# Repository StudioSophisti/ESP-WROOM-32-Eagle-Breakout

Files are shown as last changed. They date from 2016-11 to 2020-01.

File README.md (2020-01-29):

# ESP-WROOM-32-Eagle-Breakout
A breadboard compatible Eagle breakout board for Espressif's ESP32 module ESP-WROOM-32. The ESP32 is a powerful and low-cost Wifi/Bluetooth chip that enables great Internet-Of-Things applications. Studio Sophisti is using this chip in several projects, including a work-in-progress redesign of Ping (http://www.studiosophisti.nl/ping)

The ESP-WROOM-32 can be purchased directly from Espressif or from a distributor like Adafruit: https://www.adafruit.com/product/3320

The board contains reverse-voltage protections, 2 buttons (1 for reset and 1 for activating programming mode), and a diode on the RX line so the IC is 5V serial port compatible.

Power it from a 3.0-3.3V power source.

The design has been tested and works.

### Partlist

- 2 SPST switches: Farnell 2468741
- 2 10k resistors: Farnell 2130939
- 1 10uF capacitor: Farnell 2494230
- 1 1N4148 diode: Farnell 1466524
- 1 2N2007E mosfet: Farnell 2317616

### PCB Preview
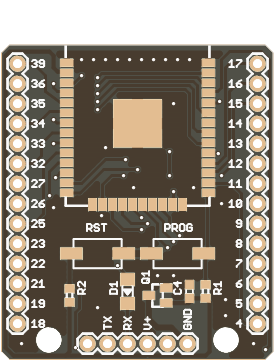
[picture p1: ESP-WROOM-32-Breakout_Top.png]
Preview


Generated with GerberTools from ThisIsNotRocketScience (https://github.com/ThisIsNotRocketScience/GerberTools), thanks Stijn!

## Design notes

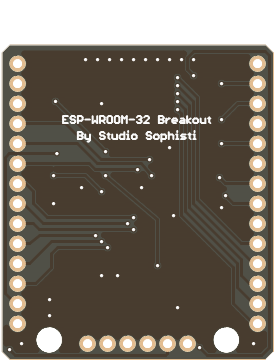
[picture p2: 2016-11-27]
ESP-WROOM-32-Breakout_Bottom.png

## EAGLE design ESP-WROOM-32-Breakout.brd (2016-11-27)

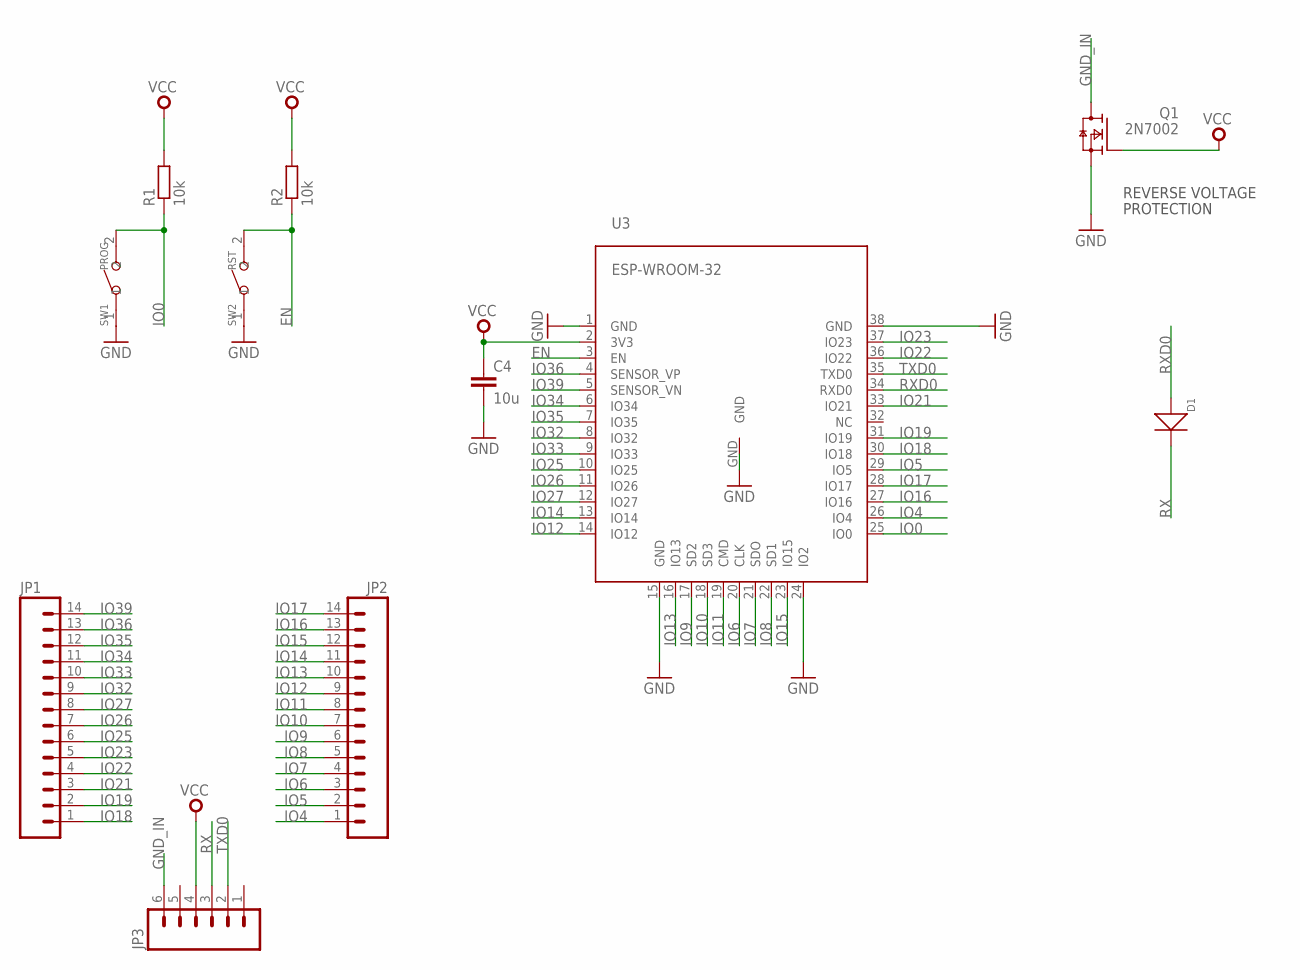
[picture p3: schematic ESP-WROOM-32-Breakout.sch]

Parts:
C4: 10u; C0603
D1: DIODE'0805'; SOD-323
JP1, JP2: M14; 1X14
JP3: M06SILK_FEMALE_PTH; 1X06
Q1: 2N7002; SOT23
R1, R2: 10k; R0603
SW1: PROG; SW2-4.0-6.0X3.0X2.5MM
SW2: RST; SW2-4.0-6.0X3.0X2.5MM
U3: ESP-WROOM-32

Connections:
EN: R2.1, SW2.2, U3.3 (EN)
GND: C4.2, Q1.2 (S), SW1.1, SW2.1, U3.1 (GND), U3.15 (GND), U3.24 (IO2), U3.38 (GND), U3.GND
GND_IN: JP3.6, Q1.3 (D)
IO0: R1.1, SW1.2, U3.25 (IO0)
IO4: JP2.1, U3.26 (IO4)
IO5: JP2.2, U3.29 (IO5)
IO6: JP2.3, U3.20 (CLK)
IO7: JP2.4, U3.21 (SDO)
IO8: JP2.5, U3.22 (SD1)
IO9: JP2.6, U3.17 (SD2)
IO10: JP2.7, U3.18 (SD3)
IO11: JP2.8, U3.19 (CMD)
IO12: JP2.9, U3.14 (IO12)
IO13: JP2.10, U3.16 (IO13)
IO14: JP2.11, U3.13 (IO14)
IO15: JP2.12, U3.23 (IO15)
IO16: JP2.13, U3.27 (IO16)
IO17: JP2.14, U3.28 (IO17)
IO18: JP1.1, U3.30 (IO18)
IO19: JP1.2, U3.31 (IO19)
IO21: JP1.3, U3.33 (IO21)
IO22: JP1.4, U3.36 (IO22)
IO23: JP1.5, U3.37 (IO23)
IO25: JP1.6, U3.10 (IO25)
IO26: JP1.7, U3.11 (IO26)
IO27: JP1.8, U3.12 (IO27)
IO32: JP1.9, U3.8 (IO32)
IO33: JP1.10, U3.9 (IO33)
IO34: JP1.11, U3.6 (IO34)
IO35: JP1.12, U3.7 (IO35)
IO36: JP1.13, U3.4 (SENSOR_VP)
IO39: JP1.14, U3.5 (SENSOR_VN)
RX: D1.-, JP3.3
RXD0: D1.+, U3.34 (RXD0)
TXD0: JP3.2, U3.35 (TXD0)
VCC: C4.1, JP3.4, Q1.1 (G), R1.2, R2.2, U3.2 (3V3)

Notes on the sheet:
REVERSE VOLTAGE
PROTECTION

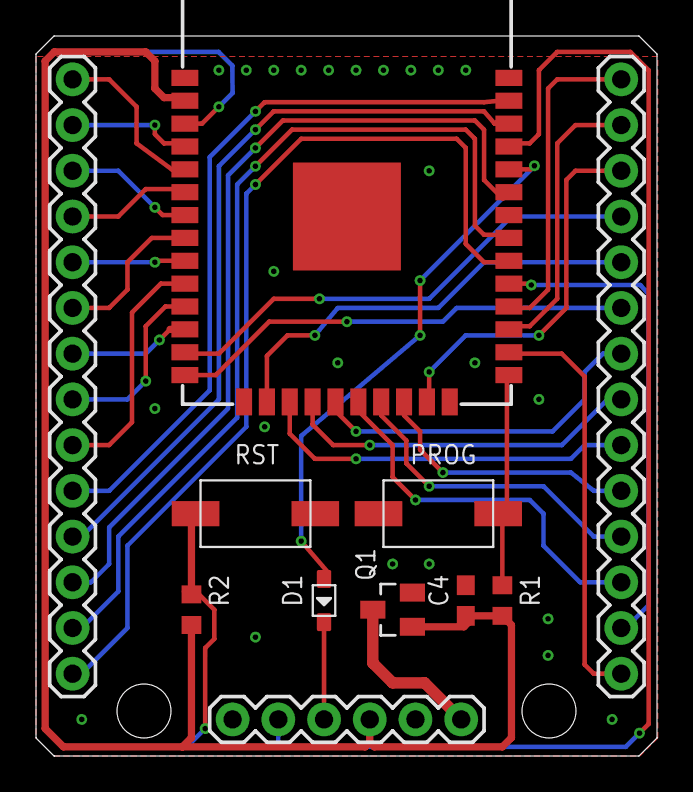
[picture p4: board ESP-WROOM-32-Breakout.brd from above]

Board: 2 copper layers, 34.5 x 40.0 mm, 11 parts (0 on the bottom side), 36 nets.

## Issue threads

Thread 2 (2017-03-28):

Replacement for 2N2007E MOSFET

ethicstechOSS, 2017-03-28:
Hi. I am unable to find stock availability of this component, 2N2007E mosfet from Farnell (Part #1894721) as well as from DigiKey. Can you suggest any replacement for this component?.

TIA,
Prakash.

tijnkooijmans, 2017-03-28:
Hi Prakash,

Thanks for noticing, indeed NXP stopt producing it but there are plenty of others. Please use this one instead: Farnell 2317616

I will update the documentation.

Best regards,
Tijn

Closed 2017-03-28.

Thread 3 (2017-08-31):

WiFi Crashing

patrick-tyger1, 2017-08-31:
I am having an issue with the WROOM crashing when WiFi is enabling. I've done some research and read elsewhere that it is likely a power supply issue however I'm not sure that's the case here. I am using the same power supply circuit as the Sparkfun ESP32 Thing and have confirmed it is able to power the official ESP32 Dev Module by connecting directly to the 3V3 and Gnd, and reading serial through an FTDI interface. The Arduino WiFiScan example works on the Dev Module but I get the following Backtrace errors when using the Breakout.

0x4008c6c6: write_txrate_power_offset at ?? line ?
0x40089651: set_tx_gain_table at ?? line ?
0x4008a5c5: bb_init at ?? line ?
0x4008ad93: register_chipv7_phy at ?? line ?
0x4010abc0: esp_phy_rf_init at /Users/ficeto/Desktop/ESP32/ESP32/esp-idf-public/components/esp32/./phy_init.c line 142
0x4010ad29: esp_phy_load_cal_and_init at /Users/ficeto/Desktop/ESP32/ESP32/esp-idf-public/components/esp32/./phy_init.c line 290
0x400ed6ab: wifi_hw_start at ?? line ?
0x400ed6e9: wifi_start_process at ?? line ?
0x400edc8a: ieee80211_ioctl_process at ?? line ?
0x400946f6: ppTask at ?? line ?

Any experience or thoughts here?

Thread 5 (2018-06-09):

why connect IO2 to GND?

ayhoung, 2018-06-09:
As you can see from this screenshot, IO2 seems to be grounded. I was wondering if there was any particular reason for this?
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

tijnkooijmans, 2018-06-11:
No reason, feel free to change!

hydronics2, 2019-05-02:
my question too!... ok. I thought I was missing a ground or looking at the wrong schematic.

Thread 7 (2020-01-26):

Error at README.md

aluis-rcastro, 2020-01-26:
Are you sure it is correct?

> Power it from a 2.2-3.6V power source

According to datasheet, it is 3.0-3.6V, unless overlooked something.

tijnkooijmans, 2020-01-29:
Hi @aluis-rcastro, you are completely right, I have updated the doc.

Closed 2020-01-29.

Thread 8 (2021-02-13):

wrong mosfet

indotronic, 2021-02-13:
2N2007E mosfet: Farnell 2317616 not 2N2007E
but 2N7002E

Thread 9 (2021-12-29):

Program not loading...

sbabadag, 2021-12-29:
Hi dear all;
I have ordered the pcs's in your design also soldered all parts as you described , but every time i try to program the mcu with uart , on arduino ide it start typing connecting but never uploads the code , did you have an issue like this or what can be wrong ? thanks.

sbabadag, 2022-01-01:
And one more question , which pin i will use to get 3.3v , your V+ seems power in.?

0xShiroKuma, 2022-07-04:
In order to program the MCU, you can try to use the JTAG debug feature (https://docs.espressif.com/projects/esp-idf/en/latest/esp32/api-guides/jtag-debugging/configure-other-jtag.html)

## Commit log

2016-11-26 first version of breakout board
    [ESP-WROOM-32-Breakout.brd, ESP-WROOM-32-Breakout.sch]
2016-11-27 smaller header pads reduced board size added mounting holes stitching via’s at antenna
    [ESP-WROOM-32-Breakout.brd, ESP-WROOM-32-Breakout.sch]
2016-11-27 improved silks
    [ESP-WROOM-32-Breakout.brd, ESP-WROOM-32-Breakout.sch]
2016-11-27 added gerbers
    [ESP-WROOM-32-Breakout.GBL, ESP-WROOM-32-Breakout.GBO, ESP-WROOM-32-Breakout.GBP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]
2016-11-27 added reverse-voltage protection
    [ESP-WROOM-32-Breakout.brd, ESP-WROOM-32-Breakout.sch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]
2016-11-27 changed diode package to SOD-323
    [ESP-WROOM-32-Breakout.brd, ESP-WROOM-32-Breakout.sch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]
2017-03-23 Add Keepout and Restrict layers under antenna trace, to remove ground plane.
2018-06-06 IO34 and IO35 are only useable as inputs (see page 7 of https://cdn.sparkfun.com/datasheets/IoT/esp32_datasheet_en.pdf); added note in symbol therefore

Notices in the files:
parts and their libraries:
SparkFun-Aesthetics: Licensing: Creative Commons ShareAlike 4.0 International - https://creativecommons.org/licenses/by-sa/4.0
